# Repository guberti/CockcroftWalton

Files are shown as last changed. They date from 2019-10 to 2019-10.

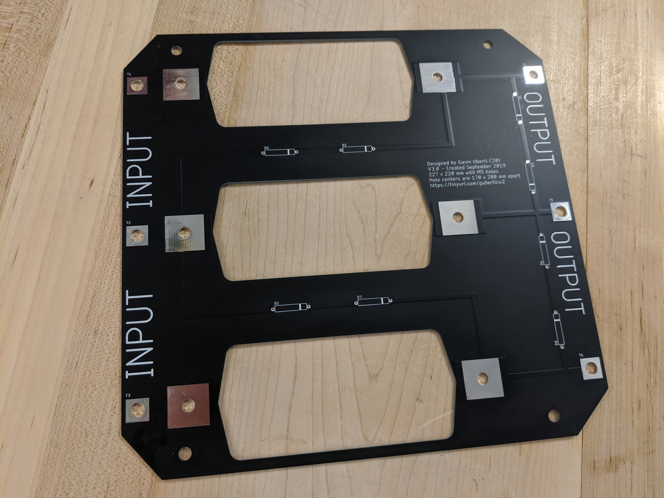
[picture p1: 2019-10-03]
photos/IMG_20190924_183515.jpg

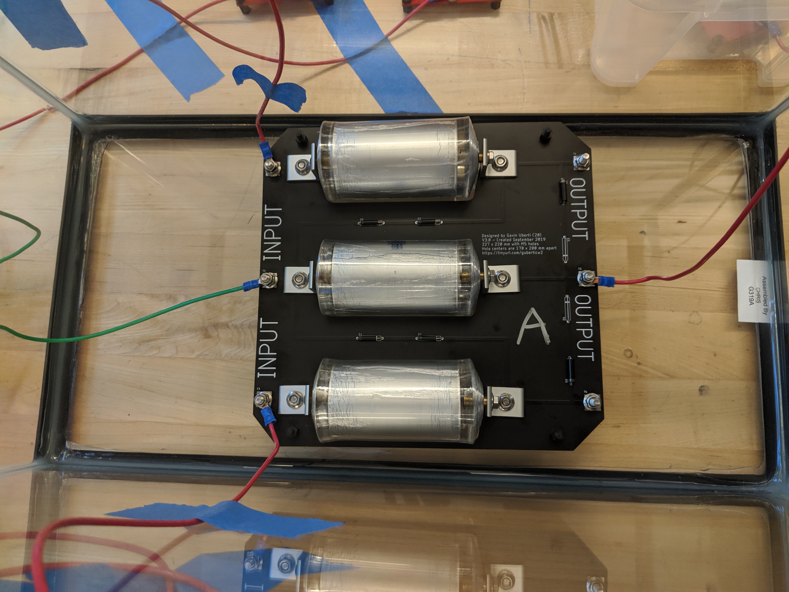
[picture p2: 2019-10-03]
photos/IMG_20191001_172126.jpg

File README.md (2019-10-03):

# 40 kV 10 mA Cockcroft-Walton Multiplier
To power a Farnsworth-Hirsch fusor me and some other [@EastsidePreparatorySchool](https://github.com/EastsidePreparatorySchool) students are building, we calculated we would need 10 mA of DC current, since the amount of radiation produced is proportional to the **square** of the voltage.

In this repo you can see the files needed to edit and order these circuit boards yourself. They are in EAGLE CAD format, and a ZIP file accepted by circuit board makers is also provided. 

The Cockcroft-Walton multiplier here is a two-stage full-wave multiplier. It is intended to be powered by a neon sign transformer that supplies 24 kV peak-to-peak AC at 30 mA in alternating phases. These are pretty cheap, and can be had on Ebay for ~$150. Note that you will need to remove the safety features of the NST before it can power these multipliers.

The circuit board, as printed, transforms this into +35 kV DC at 10 mA, though I intentionally installed the diodes backwards in my multiplier so it produces -35 kV instead (this is needed for deuterium fusion, since these ions are positively charged).


<p align="center"><i>Two stages of the soldered board. Blue jumper wires are present to stop the capacitors from building up charge.</i></p>

<p align="center"><i>The circuit board in EAGLE CAD</i></p>

<p align="center"><i>Voltage monitoring system for the CW circuit board. Note the level-shifted voltage dividers.</i></p>

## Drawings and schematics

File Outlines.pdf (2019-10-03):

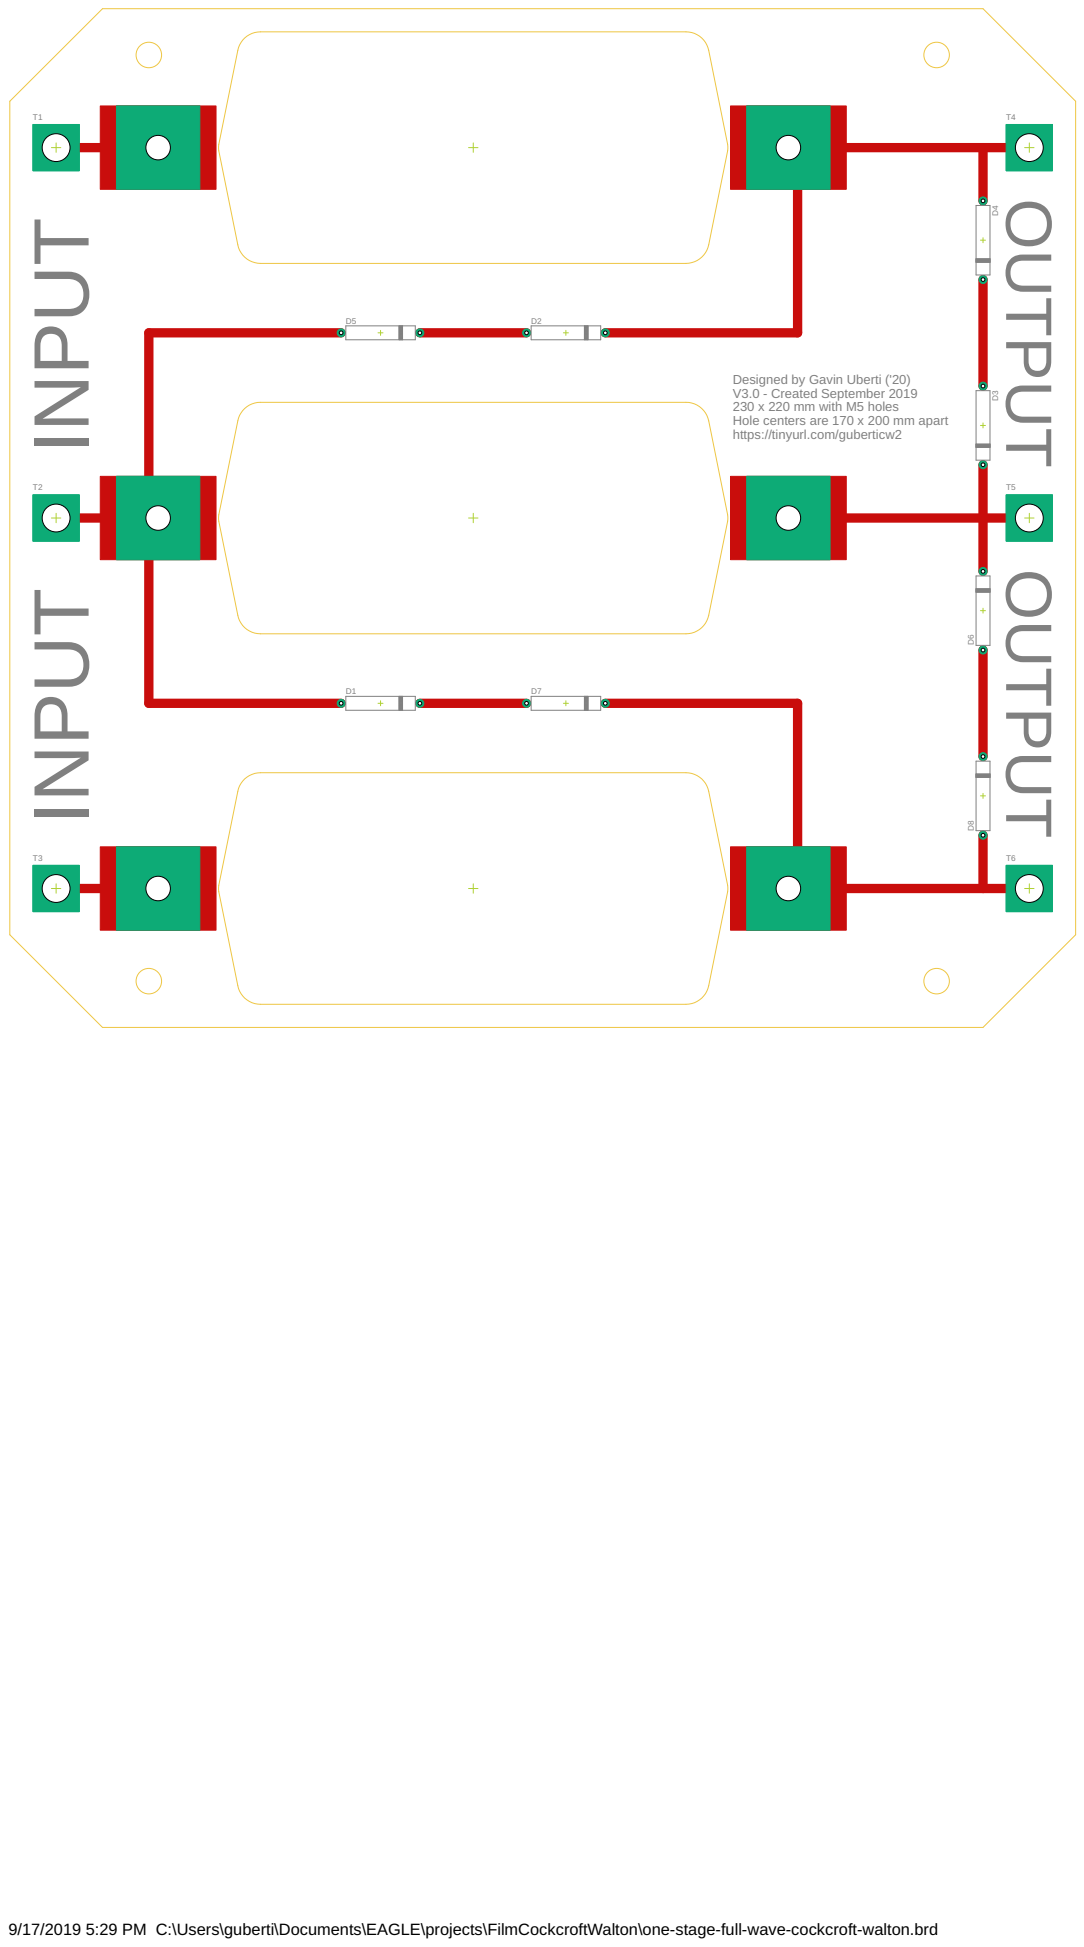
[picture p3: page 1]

Designed by Gavin Uberti ('20)
V3.0 - Created September 2019
230 x 220 mm with M5 holes Hole centers are 170 x 200 mm apart

9/17/2019 5:29 PM C:\Users\guberti\Documents\EAGLE\projects\FilmCockcroftWalton\one-stage-full-wave-cockcroft-walton.brd

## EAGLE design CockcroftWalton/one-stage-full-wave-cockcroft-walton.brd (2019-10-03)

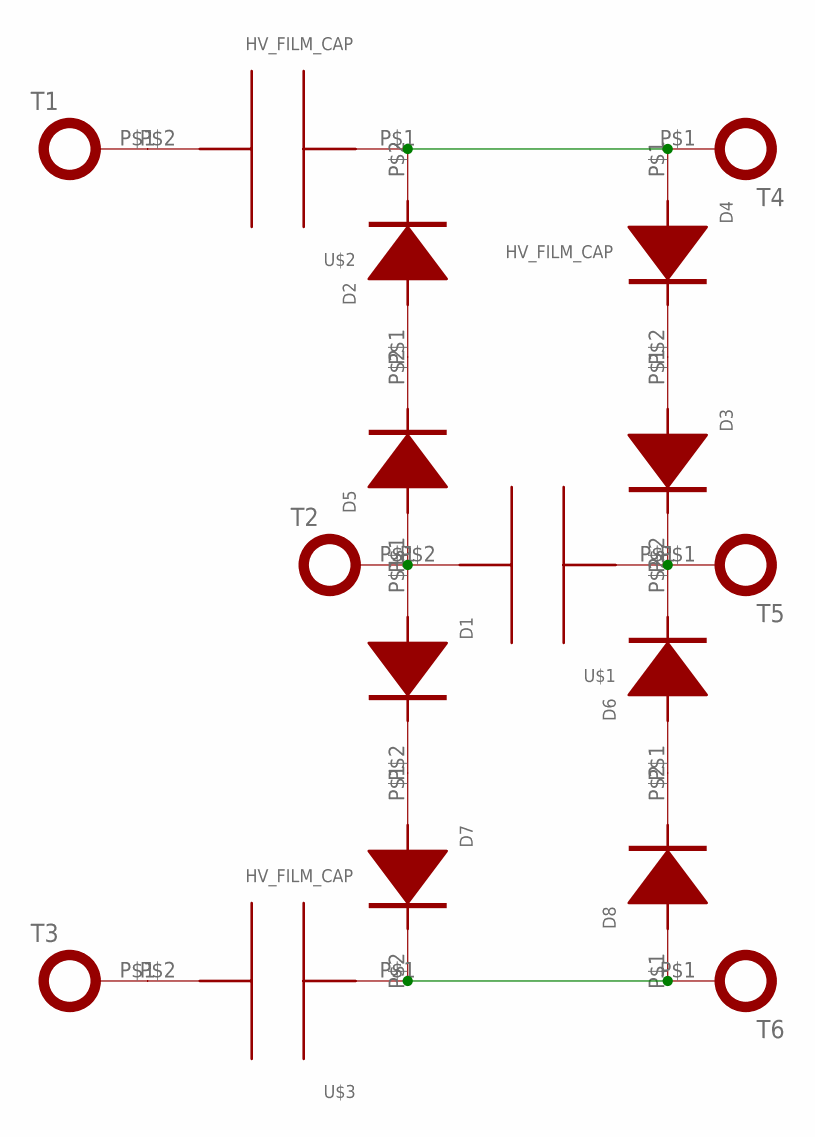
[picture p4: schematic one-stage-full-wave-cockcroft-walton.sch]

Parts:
D1, D2, D3, D4, D5, D6, D7, D8: DIODE_14MM; DIODE_14
T1, T2, T3, T4, T5, T6: TERMINAL_M6; LUG_SQUARE_M6
U$1, U$2, U$3: HV_FILM_CAP

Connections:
unnamed: D1.P$1 (ANODE), D5.P$1 (ANODE), T2.P$1, U$1.P$2
unnamed: D2.P$1 (ANODE), D5.P$2 (CATHODE)
unnamed: D2.P$2 (CATHODE), D4.P$1 (ANODE), T4.P$1, U$2.P$1
unnamed: D3.P$1 (ANODE), D4.P$2 (CATHODE)
unnamed: T3.P$1, U$3.P$2
unnamed: T1.P$1, U$2.P$2
unnamed: D7.P$2 (CATHODE), D8.P$1 (ANODE), T6.P$1, U$3.P$1
unnamed: D3.P$2 (CATHODE), D6.P$2 (CATHODE), T5.P$1, U$1.P$1
unnamed: D1.P$2 (CATHODE), D7.P$1 (ANODE)
unnamed: D6.P$1 (ANODE), D8.P$2 (CATHODE)

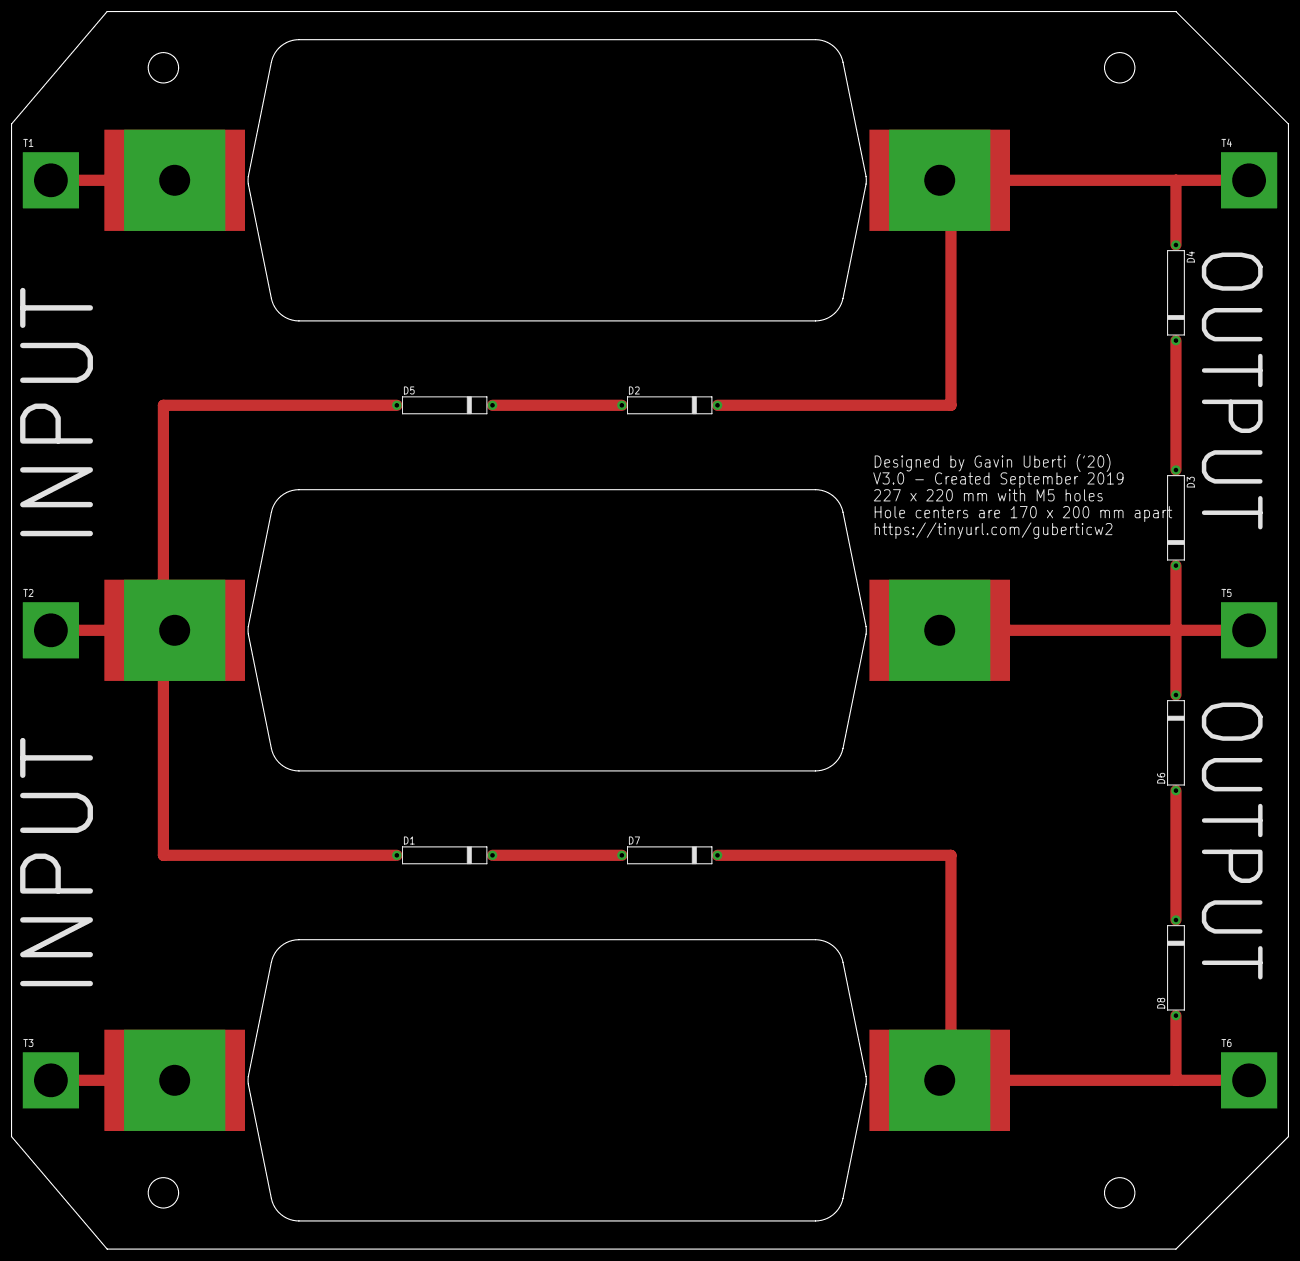
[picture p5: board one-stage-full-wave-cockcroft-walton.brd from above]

Board: 2 copper layers, 227.0 x 220.0 mm, 17 parts (0 on the bottom side), 10 nets.
